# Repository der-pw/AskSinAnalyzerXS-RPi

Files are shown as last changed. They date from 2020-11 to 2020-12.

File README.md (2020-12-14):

# AskSinAnalyzerXS-RPi     
Raspberry Pi Addon PCB für den [AskSinAnalyzerXS](https://github.com/psi-4ward/AskSinAnalyzerXS).  
Dieser wird einfach auf die GPIO-Leist gesteckt.  
Es kann der Standard Sketch (AskSinSniffer328P) aus dem [AskSinAnalyzer](https://github.com/jp112sdl/AskSinAnalyzer) Repo von Jérôme geflashed werden.  

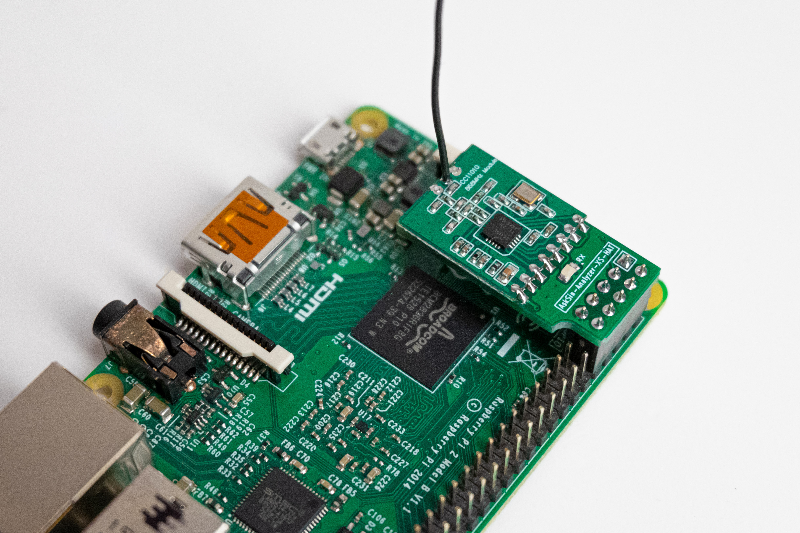
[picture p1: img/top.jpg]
Draufsicht


Im Prinzip kann der AskSinAnalyzerXS-RPi nach dem Zusammenbau mit einem Programmer (FTDI) verbunden und geflashed werden.
Der 3V Jumper kann gebrückt werden, damit die Stromversorgung vom FTDI erfolgt. DTR kann ebenfalls gebrückt werden um Reset auszulösen.
Der 0.1uF in der DTR Strecke ist nicht auf dem PCB vorhanden und sollte ins Verbindungskabel integriert werden. Alternativ kann auch Reset im richtigen Moment kurz gegen GND gebrückt werden.  
Nach erfolgreichem Flashvorgang und ersten Ausgaben auf der serielen Konsole, müssen die Lötbrücken wieder entfernt werden, bevor die Platine auf den Raspberry Pi gesteckt wird.

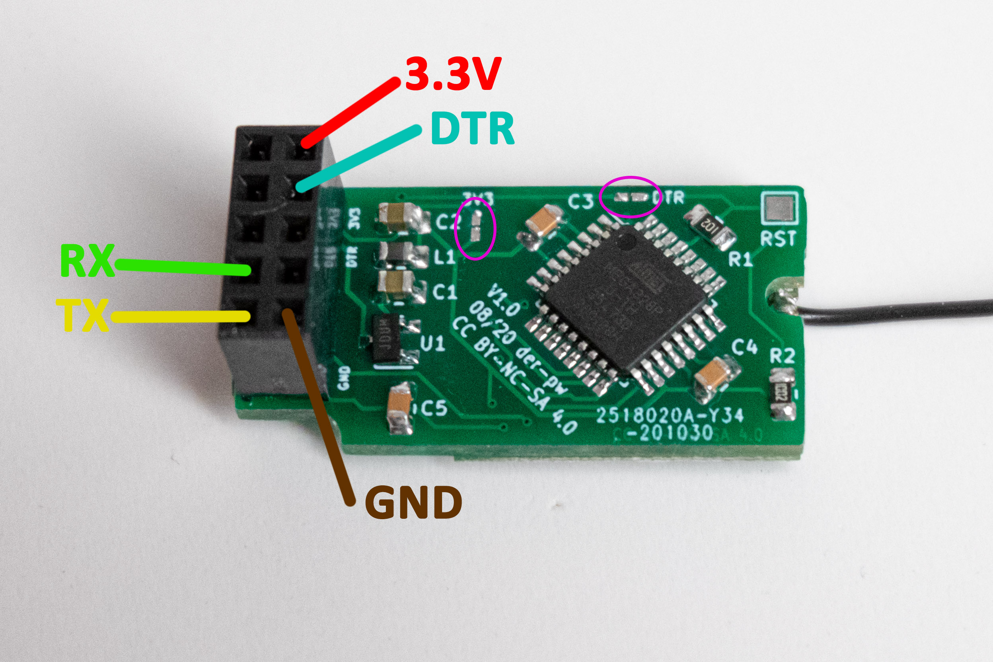
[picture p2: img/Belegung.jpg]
Unterseite
  

Folgender Tipp ist möglicherweise hilfreich, bei Verwendung der seriellen Schnittstellen auf dem RPi.  
https://homematic-forum.de/forum/viewtopic.php?f=76&t=56395&start=70#p569429 

  
Dieses Werk ist lizenziert unter einer [Creative Commons Namensnennung - Nicht-kommerziell - Weitergabe unter gleichen Bedingungen 4.0 International Lizenz](http://creativecommons.org/licenses/by-nc-sa/4.0/).

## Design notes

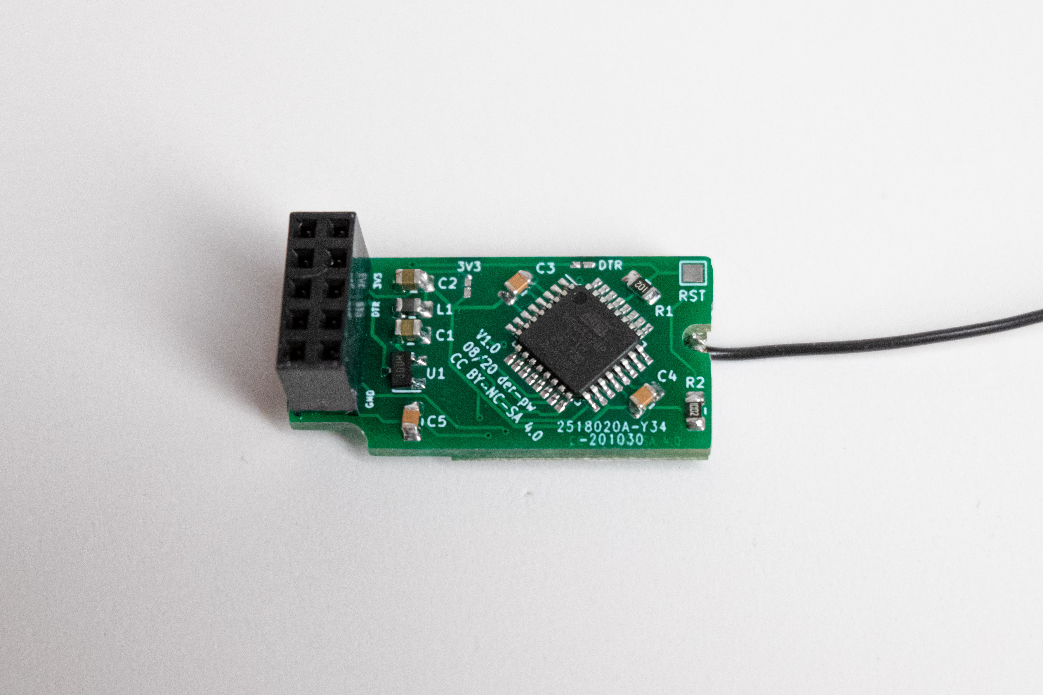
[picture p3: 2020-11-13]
img/bottom.jpg

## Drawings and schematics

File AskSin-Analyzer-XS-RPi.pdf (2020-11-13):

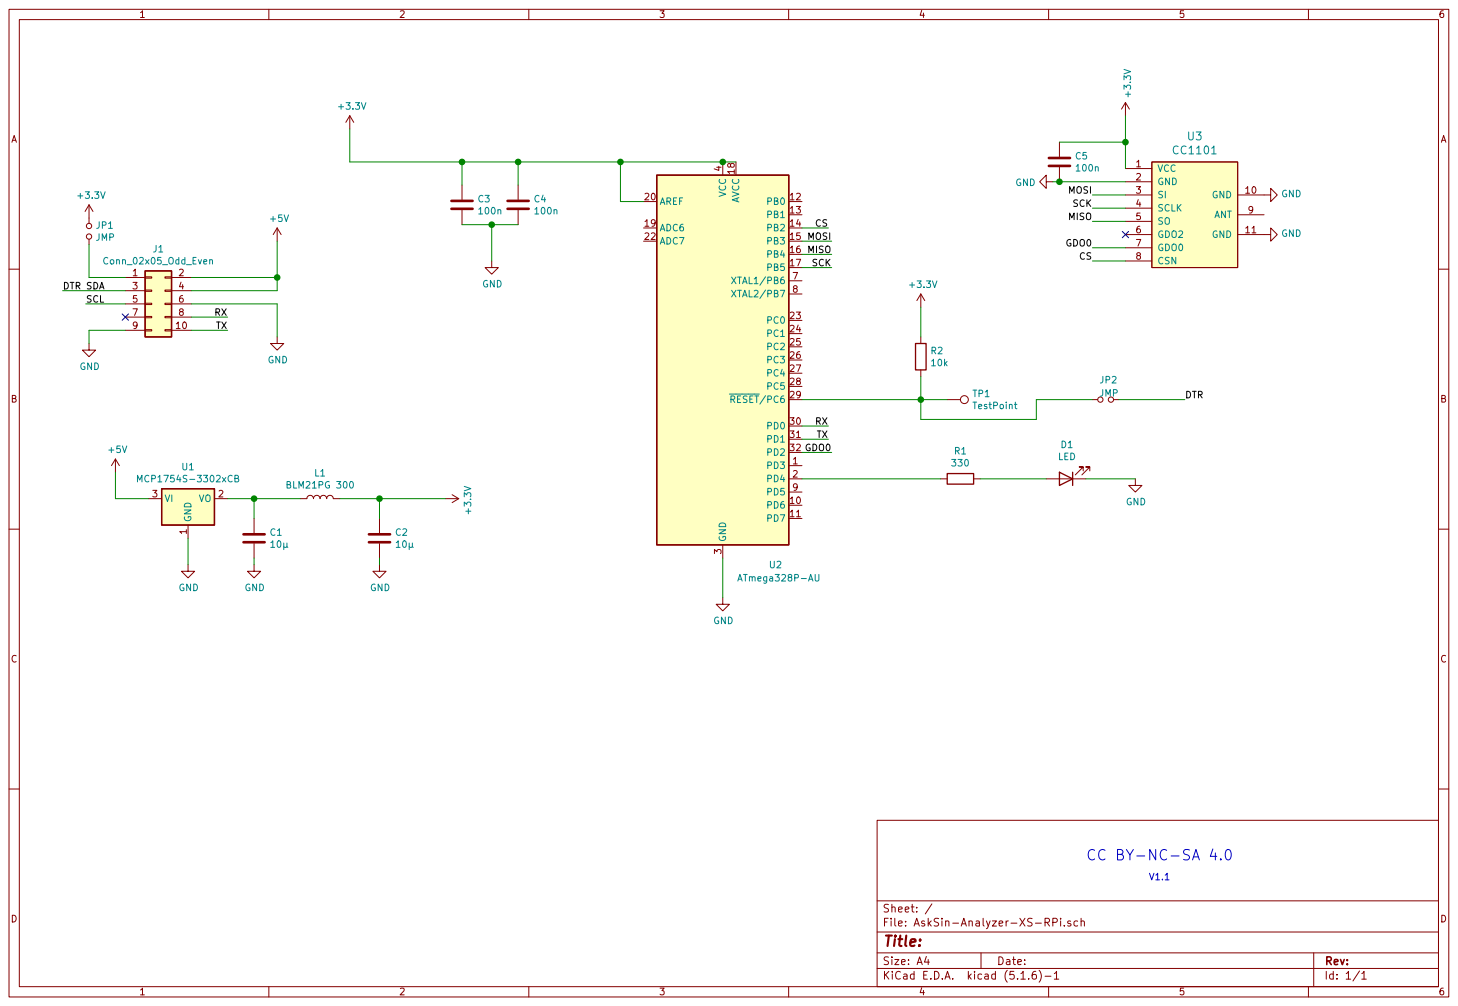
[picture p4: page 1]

1 VO 2 VI 3 U1 MCP1754S-3302xCB GND GND

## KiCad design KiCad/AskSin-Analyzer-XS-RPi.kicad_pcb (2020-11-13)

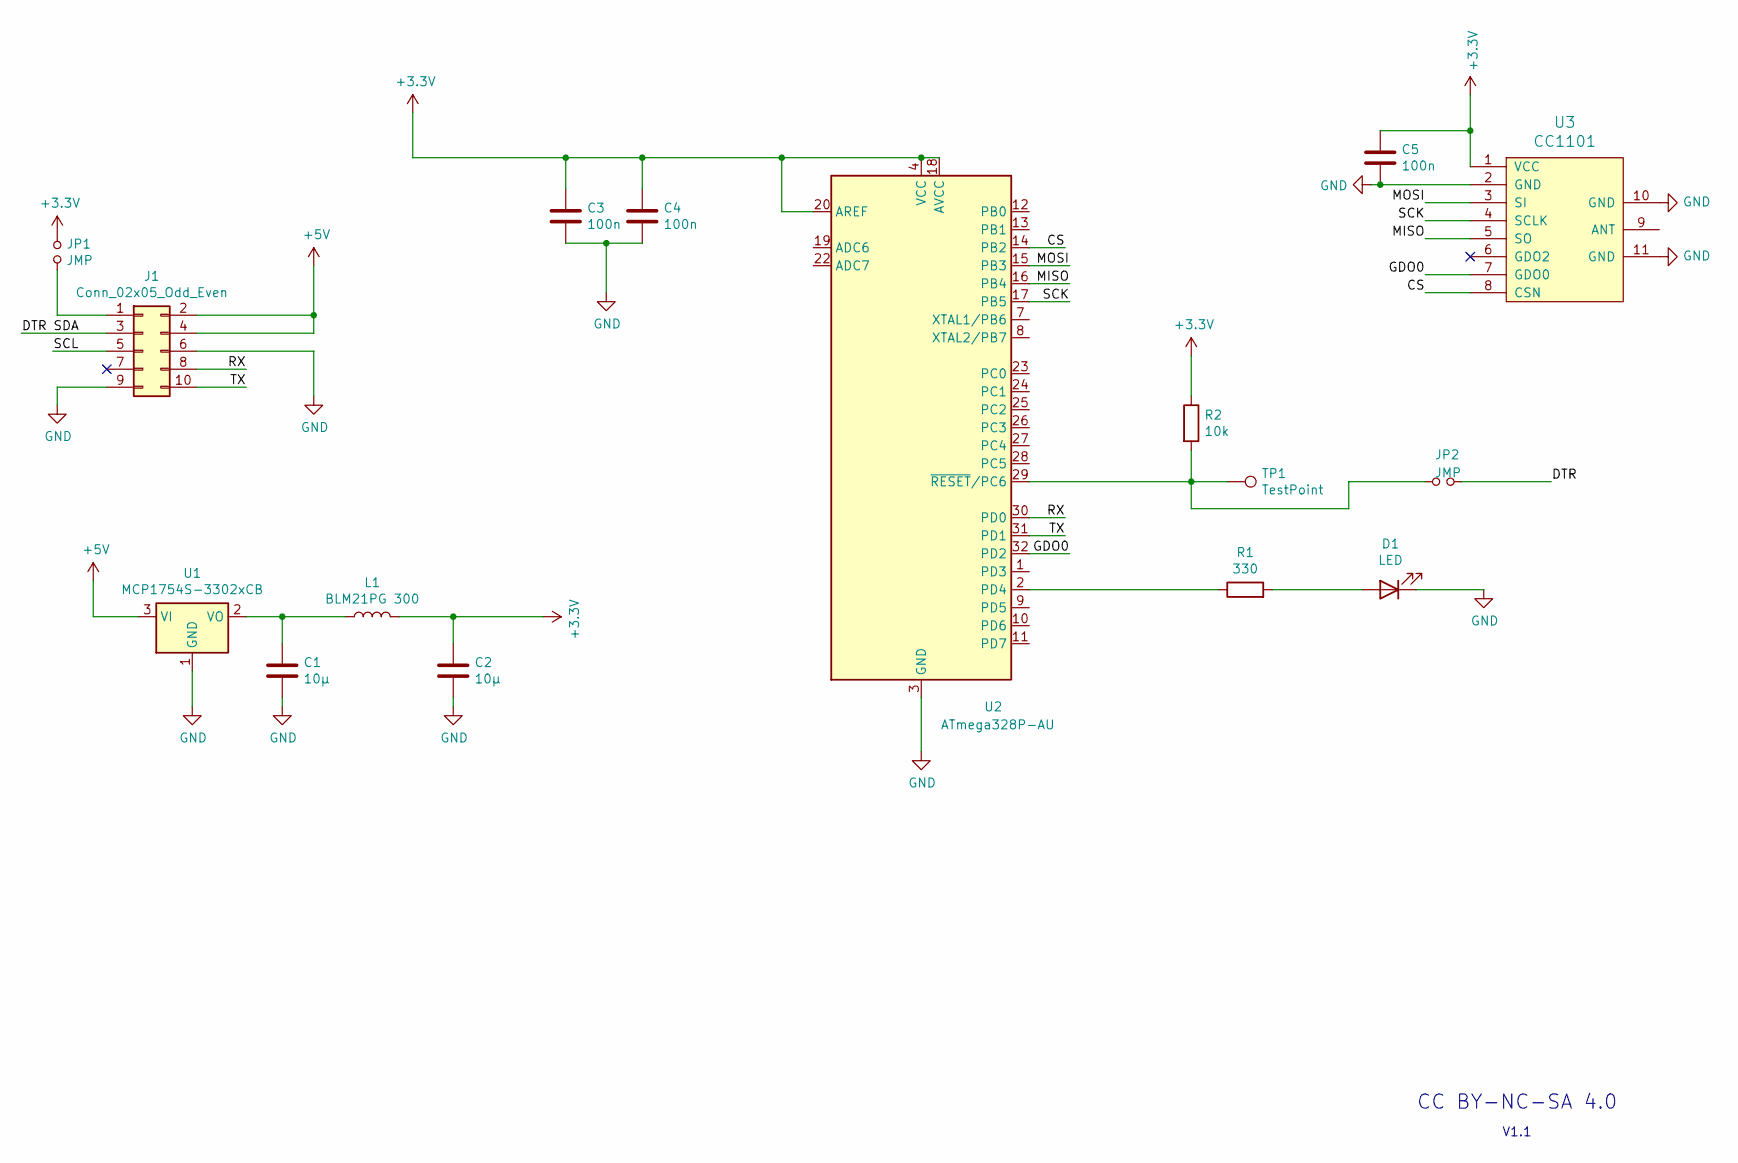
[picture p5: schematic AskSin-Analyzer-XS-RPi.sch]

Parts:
C1, C2: 10µ; C_0805_2012Metric_Pad1.15x1.40mm_HandSolder
C3, C4, C5: 100n; C_0805_2012Metric_Pad1.15x1.40mm_HandSolder
D1: LED; LED_0805_2012Metric_Pad1.15x1.40mm_HandSolder
J1: Conn_02x05_Odd_Even; PinHeader_2x05_P2.54mm_Vertical
JP1, JP2: JMP; my_mini_Jumper
L1: BLM21PG 300; L_0805_2012Metric_Pad1.15x1.40mm_HandSolder
R1: 330; R_0805_2012Metric_Pad1.15x1.40mm_HandSolder
R2: 10k; R_0805_2012Metric_Pad1.15x1.40mm_HandSolder
TP1: TestPoint; TestPoint_Pad_2.0x2.0mm
U1: MCP1754S-3302xCB; SOT-23
U2: ATmega328P-AU; TQFP-32_7x7mm_P0.8mm
U3: CC1101; CC1101_Module_HM-Sensor

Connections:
+3V3: C2.1, C3.1, C4.1, C5.1, JP1.1, L1.2, R2.1, U2.4 (VCC), U2.6 (VCC), U2.18 (AVCC), U2.20 (AREF), U3.1 (VCC)
+5V: J1.2, J1.4, U1.3 (VI)
/CS: U2.14 (PB2), U3.8 (CSN)
/DTR: J1.3, JP2.2
/GDO0: U2.32 (PD2), U3.7 (GDO0)
/MISO: U2.16 (PB4), U3.5 (SO)
/MOSI: U2.15 (PB3), U3.3 (SI)
/RX: J1.8, U2.30 (PD0)
/SCK: U2.17 (PB5), U3.4 (SCLK)
/SCL: J1.5
/TX: J1.10, U2.31 (PD1)
GND: C1.2, C2.2, C3.2, C4.2, C5.2, D1.1 (K), J1.6, J1.9, U1.1 (GND), U2.3 (GND), U2.5 (GND), U2.21 (GND), U3.2 (GND), U3.10 (GND), U3.11 (GND)
unnamed: C1.1, L1.1, U1.2 (VO)
unnamed: D1.2 (A), R1.2
unnamed: J1.1, JP1.2
unnamed: JP2.1, R2.2, TP1.1, U2.29 (~RESET~/PC6)
unnamed: R1.1, U2.2 (PD4)

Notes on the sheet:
CC BY-NC-SA 4.0
V1.1

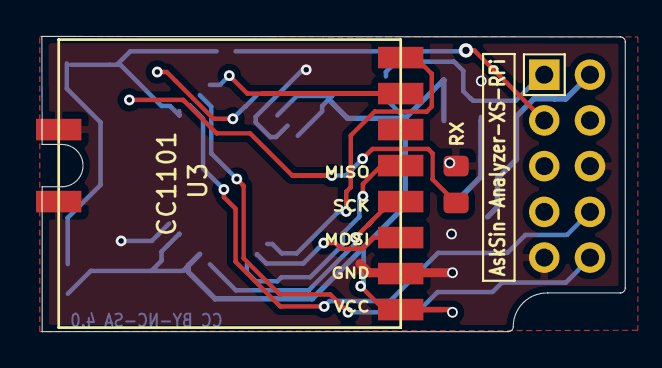
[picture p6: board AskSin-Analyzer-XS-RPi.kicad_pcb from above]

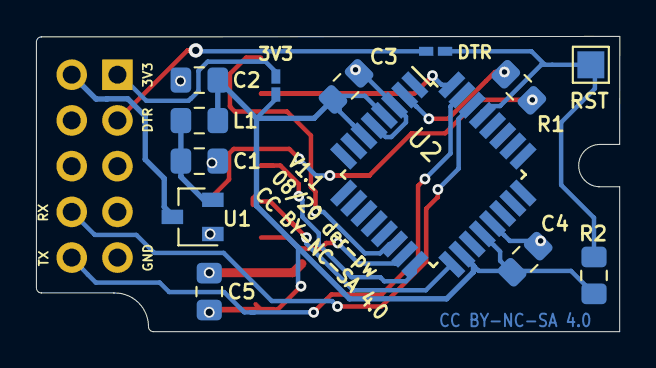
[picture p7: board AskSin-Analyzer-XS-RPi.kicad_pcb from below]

Board: 2 copper layers, 32.4 x 16.4 mm, 16 parts (13 on the bottom side), 16 nets.

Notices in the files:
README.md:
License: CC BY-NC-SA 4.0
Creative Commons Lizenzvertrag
